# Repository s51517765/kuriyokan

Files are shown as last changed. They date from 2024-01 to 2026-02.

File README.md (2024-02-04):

# Kuriyokan

## 概要 (Overview)

クレジットカードサイズのキーボード

## 実物イメージ (Image)

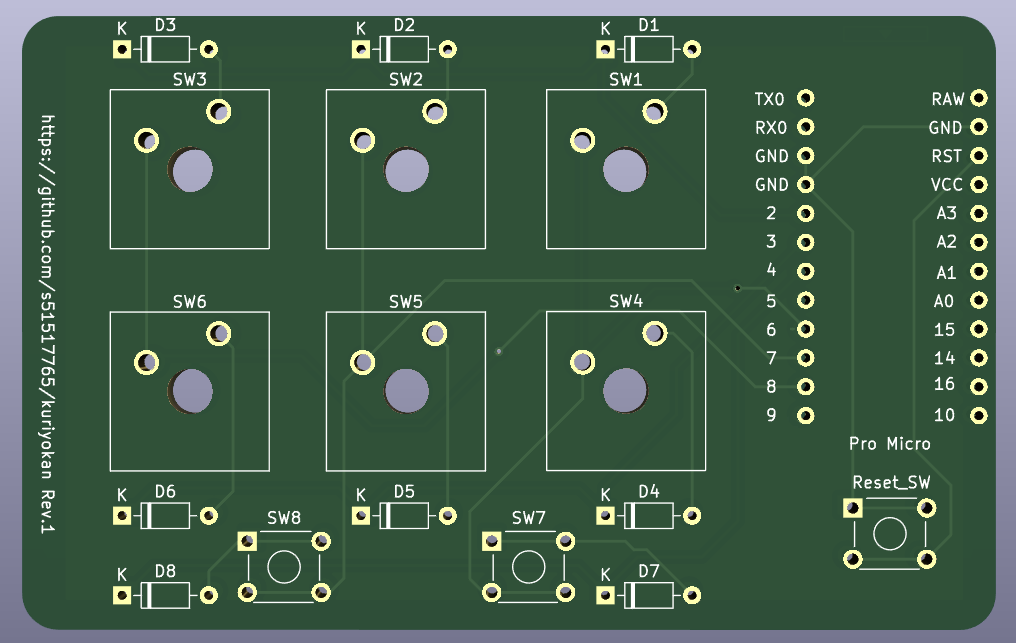
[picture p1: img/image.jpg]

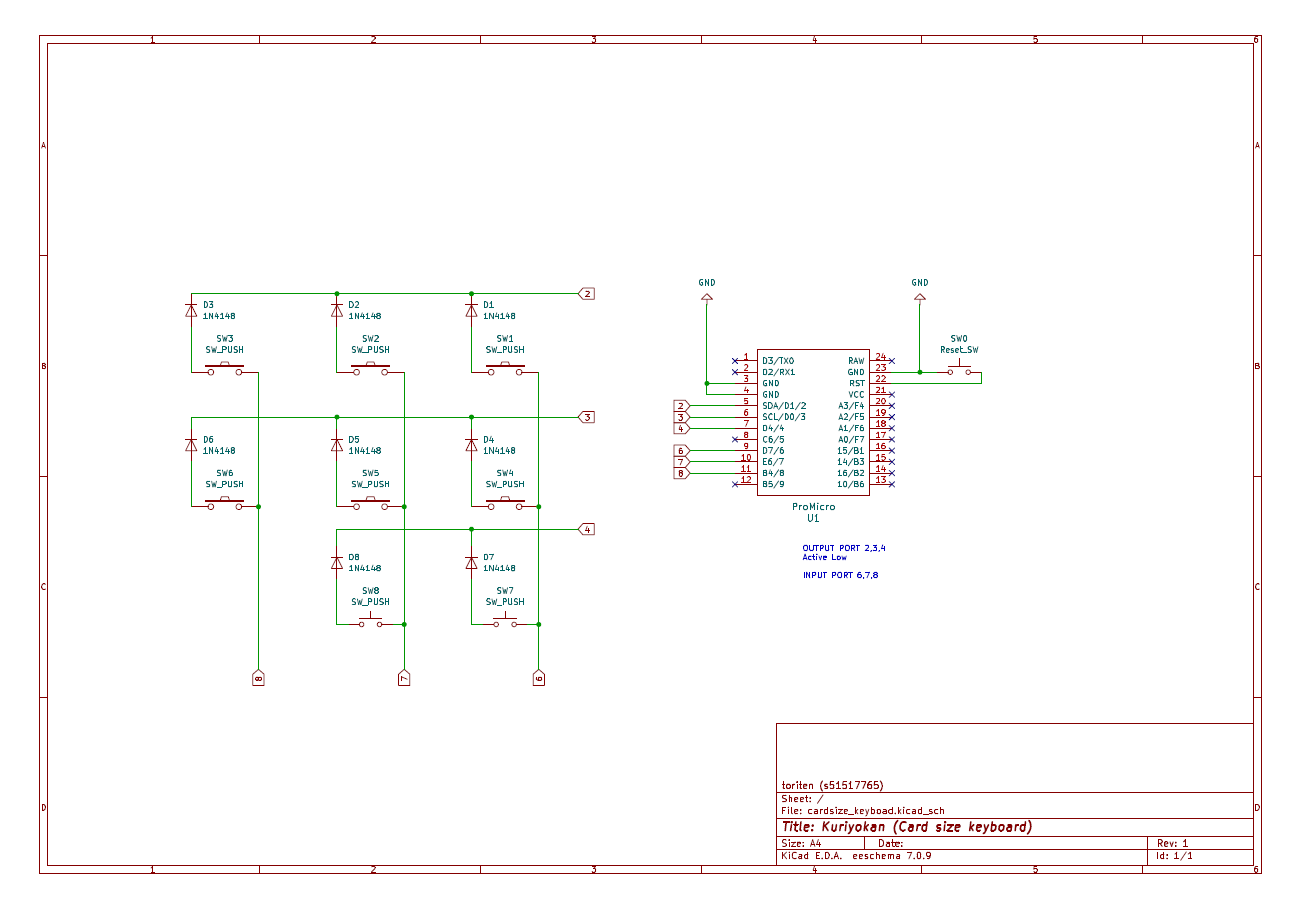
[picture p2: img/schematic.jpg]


## 技術的解説 (Technical explanation)

## 部品リスト（Parts list）

| 部品 | 種類 | 数量 |
| --- | --- | ---- |
| PCB | - | 1 |
| マイコン | Pro Mocro | 1 |
| ピンヘッダ | 12pin | 2 |
| キーボードスイッチ | Cherry MX 互換 | 6 |
| キーキャップ | Cherry MX 互換 | 6 |
| タクトスイッチ | 6mm 角 | 3 |
| ダイオード | 1N4148 | 8 |

## ライセンス (License)

This software is released under the MIT License, see LICENSE.

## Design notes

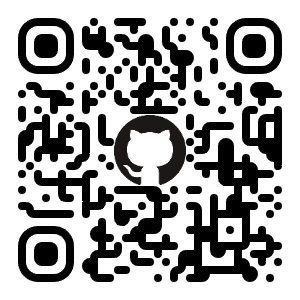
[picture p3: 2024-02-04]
img/QR.png

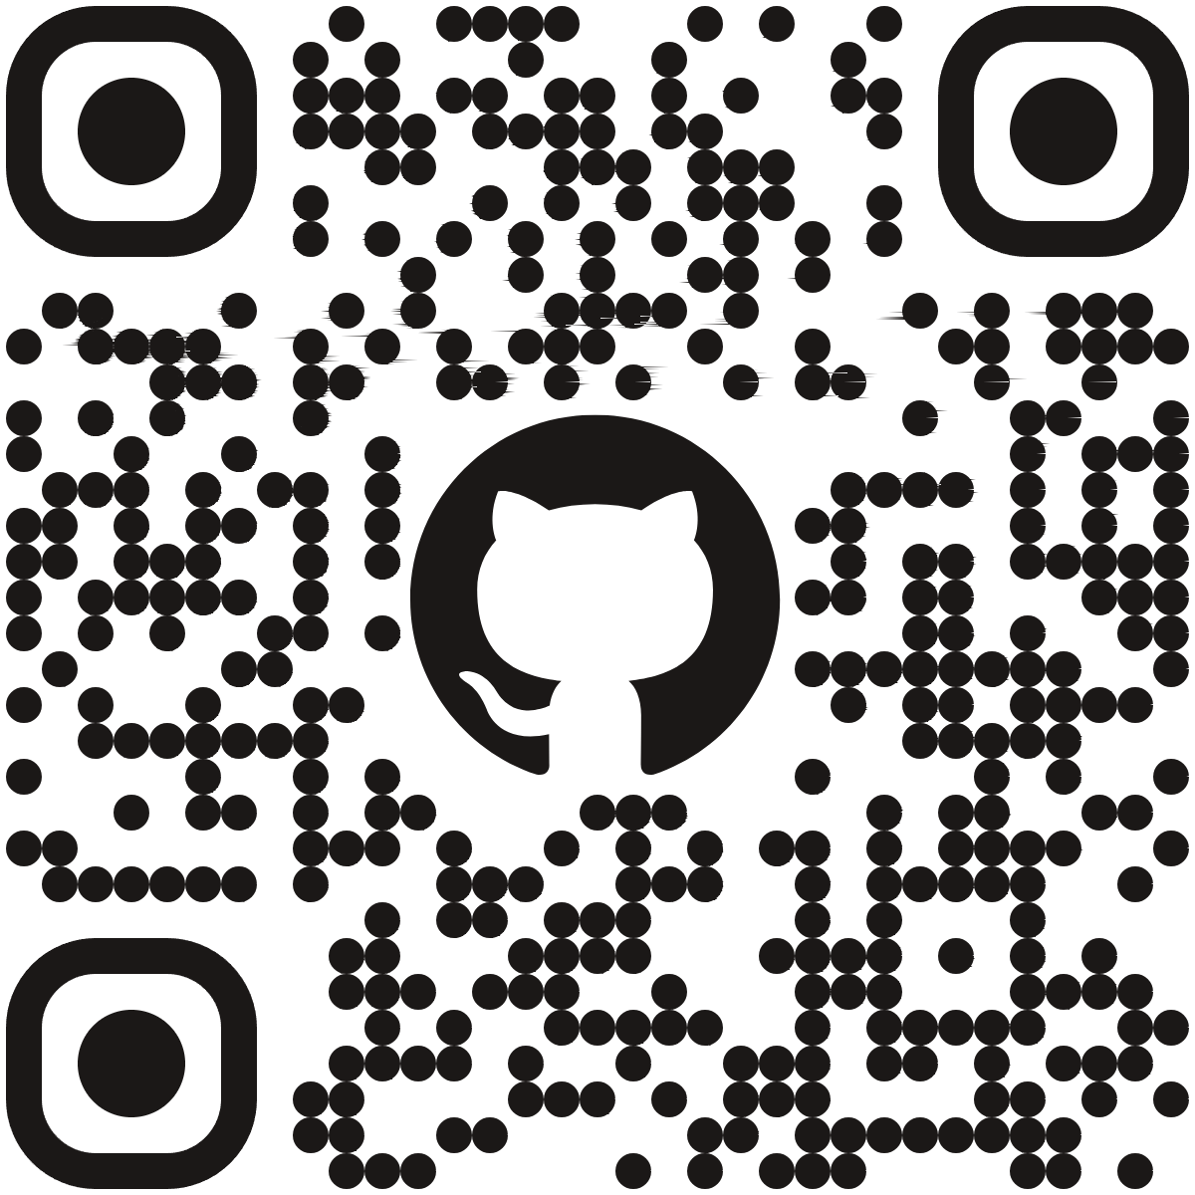
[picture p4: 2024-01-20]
garber/QR.png

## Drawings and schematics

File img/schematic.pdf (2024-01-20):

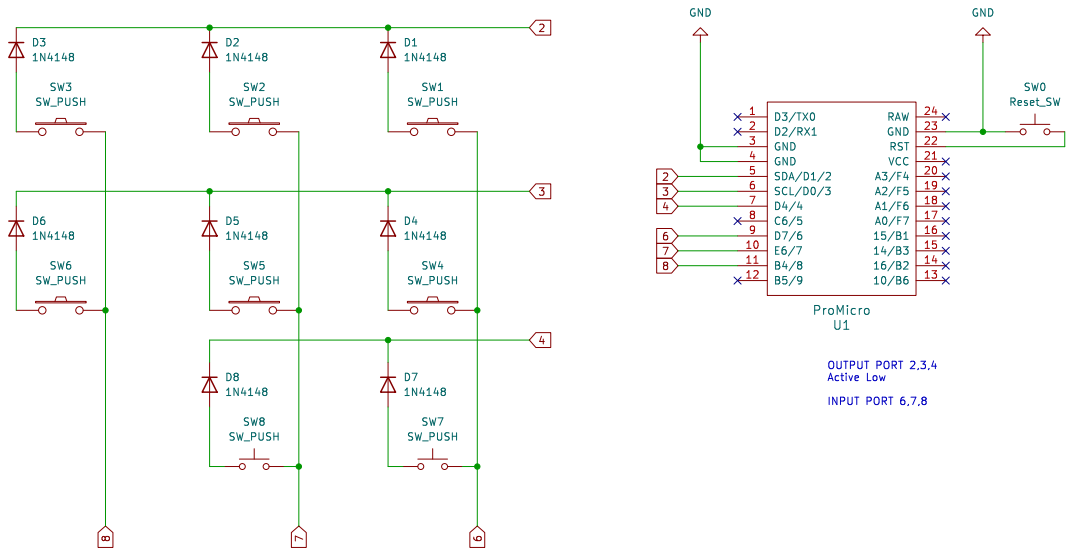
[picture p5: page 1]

Id: 1/1 Title: Kuriyokan (Card size keyboard) File: cardsize_keyboad.kicad_sch Sheet: / toriten (s51517765)

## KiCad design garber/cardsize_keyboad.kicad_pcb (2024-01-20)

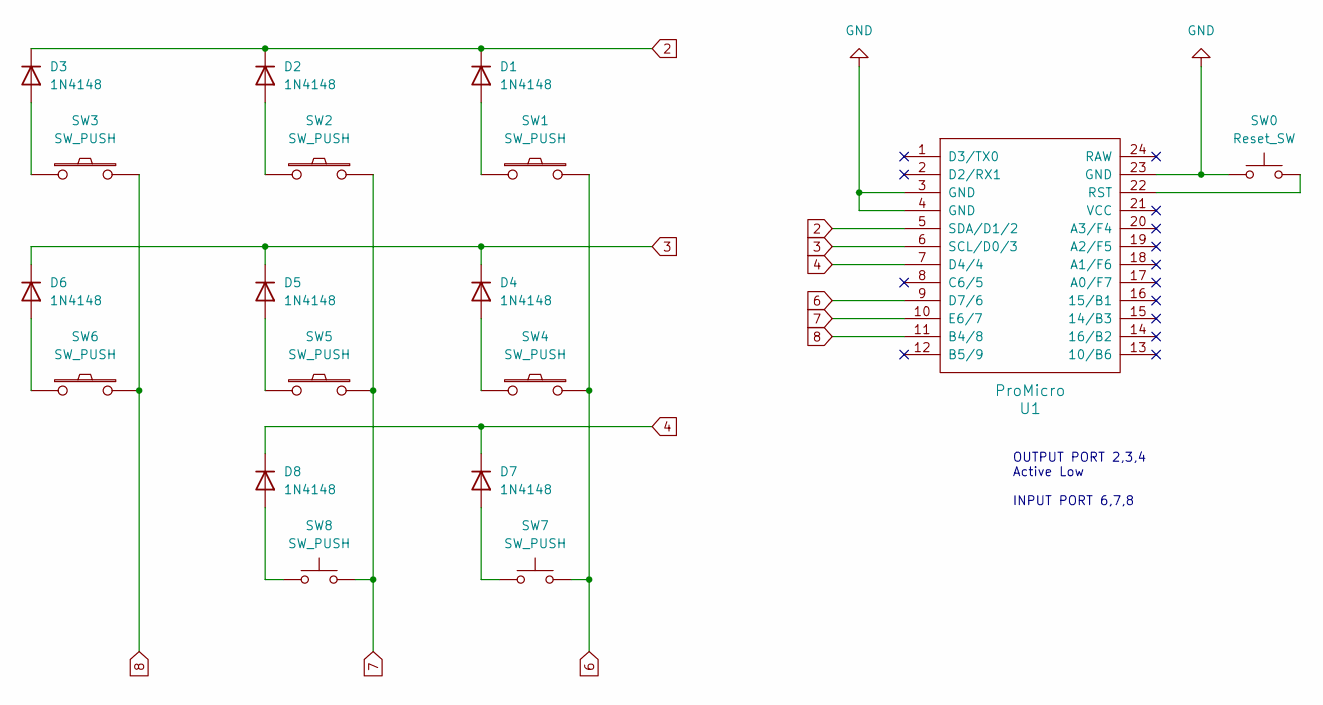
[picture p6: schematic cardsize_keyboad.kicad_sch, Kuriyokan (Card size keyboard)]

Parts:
D1, D2, D3, D4, D5, D6, D7, D8: 1N4148; D_DO-35_SOD27_P7.62mm_Horizontal
SW0: Reset_SW; SW_TH_Tactile_Omron_B3F-10xx
SW1, SW2, SW3, SW4, SW5, SW6: SW_PUSH; SW_Cherry_MX_1.00u_Plate
SW7, SW8: SW_PUSH; SW_TH_Tactile_Omron_B3F-10xx
U1: ProMicro; ProMicro_v3

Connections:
6: SW1.2, SW4.2, SW7.2, U1.9 (D7/6)
7: SW2.2, SW5.2, SW8.2, U1.10 (E6/7)
8: SW3.2, SW6.2, U1.11 (B4/8)
GND: SW0.1, U1.3 (GND), U1.4 (GND), U1.23 (GND)
unnamed: D1.2 (A), SW1.1
unnamed: D1.1 (K), D2.1 (K), D3.1 (K), U1.5 (SDA/D1/2)
unnamed: D2.2 (A), SW2.1
unnamed: D3.2 (A), SW3.1
unnamed: D4.2 (A), SW4.1
unnamed: D4.1 (K), D5.1 (K), D6.1 (K), U1.6 (SCL/D0/3)
unnamed: D5.2 (A), SW5.1
unnamed: D6.2 (A), SW6.1
unnamed: D7.2 (A), SW7.1
unnamed: D7.1 (K), D8.1 (K), U1.7 (D4/4)
unnamed: D8.2 (A), SW8.1
unnamed: SW0.2, U1.22 (RST)

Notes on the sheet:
OUTPUT PORT 2,3,4 Active Low INPUT PORT 6,7,8

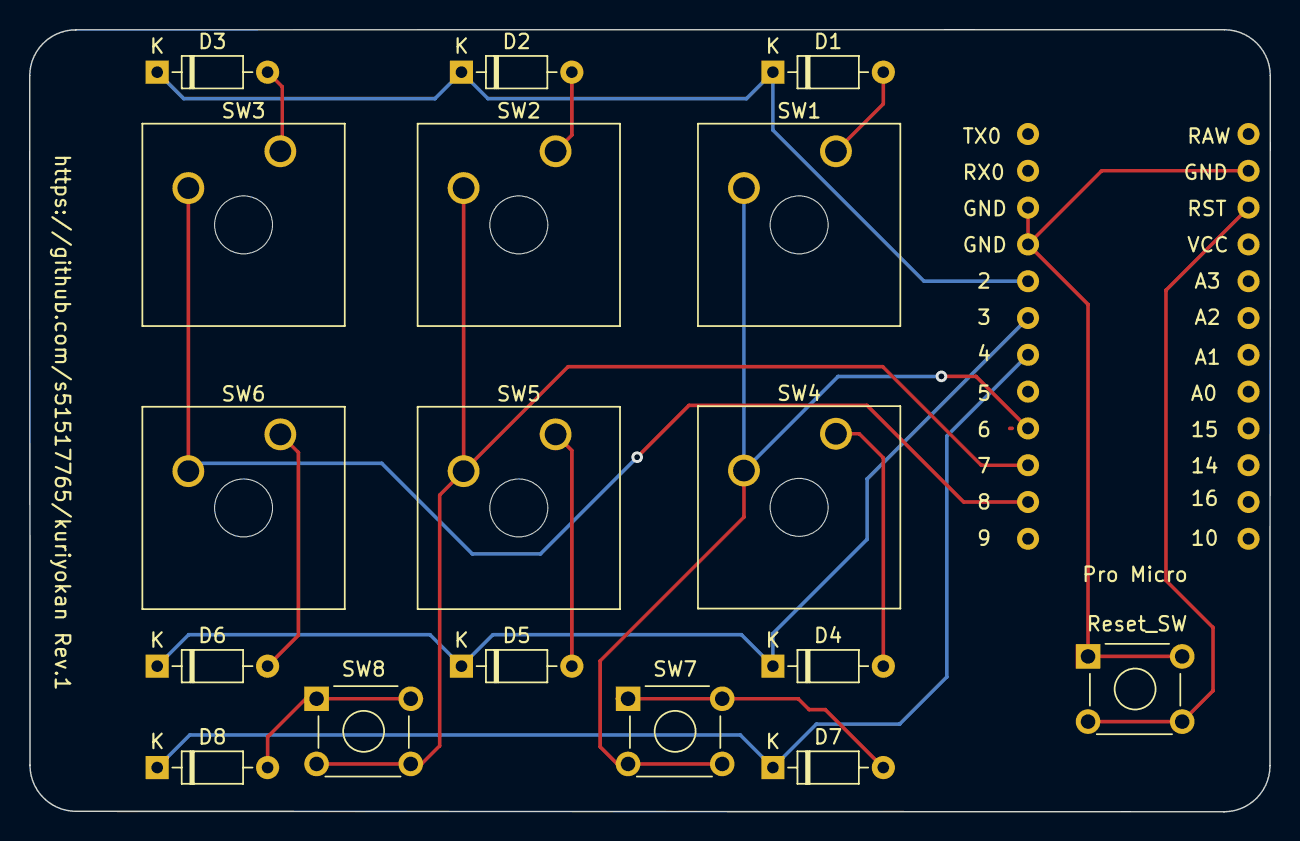
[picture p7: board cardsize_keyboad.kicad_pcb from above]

Board: 2 copper layers, 85.6 x 54.0 mm, 18 parts (1 on the bottom side), 16 nets.

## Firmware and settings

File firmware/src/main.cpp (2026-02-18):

// 認識しないとき、RSTをGNDに2回
// 書き込めないとき、書き込み始めたらRSTをGNDに1回

#include <Keyboard.h>
#include <Mouse.h>
#include "setting.h"

#define BUILTIN_LED 30

const uint8_t OUTPUT_PORT[] = {2, 3, 4}; // 2,3,4
const uint8_t INPUT_PORT[] = {8, 7, 6};  // 5,6,7,8
const uint8_t CN = pow(2, (sizeof(INPUT_PORT) / sizeof(uint8_t)) - 1);

#define MAX_PAGE 2
#define SW_COUNT 9
const uint16_t key_codes[MAX_PAGE][SW_COUNT] = {{SW01, SW02, SW03, SW04, SW05, SW06, SW07, SW08, SW00}, {SW11, SW12, SW13, SW14, SW15, SW16, SW17, SW18, SW10}};
uint8_t key_map_page = 0;

// 文字列定義 必要に応じてサイズは拡大可能
const uint8_t str_codes[2][8] = {{0x6b, 0x75, 0x72, 0x69, KEY_RETURN, NONE, NONE, NONE}, {NONE, NONE, NONE, NONE, NONE, NONE, NONE, NONE}};

void debug_print(uint16_t code)
{
    if (DEBUG_ENABLE)
    {
        Serial.print("0x");
        Serial.println(code, HEX);
    }
}

void setup()
{
    for (uint8_t i = 0; i < sizeof(OUTPUT_PORT); i++)
    {
        pinMode(OUTPUT_PORT[i], OUTPUT);
        digitalWrite(OUTPUT_PORT[i], HIGH);
    }
    for (uint8_t i = 0; i < sizeof(INPUT_PORT); i++)
    {
        pinMode(INPUT_PORT[i], INPUT_PULLUP);
    }
    Keyboard.releaseAll();
    if (DEBUG_ENABLE)
    {
        Serial.begin(115200);
    }
    else
    {
        pinMode(BUILTIN_LED, INPUT);
    }
    //ホイールスクロール用
    Mouse.begin();
}

uint16_t key_scan()
{
    uint16_t key_pressed = 0;
    for (uint8_t col = 0; col < sizeof(OUTPUT_PORT); col++)
    {
        digitalWrite(OUTPUT_PORT[col], LOW);
        uint16_t row_data = 0;
        for (uint8_t row = 0; row < sizeof(INPUT_PORT); row++)
        {
            row_data |= (digitalRead(INPUT_PORT[row]) ? 0 : CN >> row);
        }
        key_pressed |= (row_data << (sizeof(INPUT_PORT) * col));
        digitalWrite(OUTPUT_PORT[col], HIGH);
    }
    return key_pressed;
}

void loop()
{
    static uint8_t last_key_pressed = 0;
    uint16_t key_pressed = key_scan();
    uint16_t change = key_pressed ^ last_key_pressed;
    if (change)
    {
        uint16_t mask = 1;
        uint16_t code;

        for (uint8_t i = 0; i < sizeof(key_codes[0]); i++)
        {
            if (change & mask)
            {
                code = key_codes[key_map_page][i];

                if (key_pressed & mask)
                {
                    if (code == KEY_MAP_PAGE_TOGGLE)
                    {
                        key_map_page = (key_map_page + 1) % MAX_PAGE;
                        debug_print(0xFFFF);
                    }
                    else if((code & 0x2000) !=0){
                        // ホイールスクロール
                        switch(code)
                        {
                        case WHEEL_SCROLL_UP:
                            Mouse.move(0, 0, 1); // 上スクロール
                            break;
                        case WHEEL_SCROLL_DOWN:
                            Mouse.move(0, 0, -1); // 上スクロール
                            break;
                        case WHEEL_SCROLL_UP_CTRL: 
                            Keyboard.press(KEY_LEFT_CTRL);    
                            Mouse.move(0, 0, 1); // 上スクロール
                            break;
                        case WHEEL_SCROLL_UP_SHIFT:
                            Keyboard.press(KEY_LEFT_SHIFT);   
                            Mouse.move(0, 0, 1); // 上スクロール    
                            break;
                        case WHEEL_SCROLL_DOWN_CTRL:
                            Keyboard.press(KEY_LEFT_CTRL);    
                            Mouse.move(0, 0, -1); // 下スクロール
                            break;
                        case WHEEL_SCROLL_DOWN_SHIFT:
                            Keyboard.press(KEY_LEFT_SHIFT);   
                            Mouse.move(0, 0, -1); // 下スクロール
                            break;
                        default:
                            break;
                        }
                    }
                    else if ((code & STR_0) != 0)
                    {
                        // 文字列
                        for (uint8_t i = 0; i < sizeof(str_codes[0]) / sizeof(str_codes[0][0]); i++)
                        {
                            Keyboard.press(str_codes[code & 0x0F][i]);
                            debug_print(str_codes[code & 0x0F][i]);
                            delay(10);
                        }
                    }
                    else if (code == CTRL_ALT_DELETE)
                    {
                        Keyboard.press(KEY_LEFT_CTRL);
                        Keyboard.press(KEY_LEFT_ALT);
                        Keyboard.press(KEY_DELETE);
                    }
                    else if (code & 0x100)
                    {
                        Keyboard.press(KEY_LEFT_CTRL);
                    }
                    else if (code & 0x200)
                    {
                        Keyboard.press(KEY_LEFT_SHIFT);
                    }
                    else if (code & 0x400)
                    {
                        Keyboard.press(KEY_LEFT_GUI); // WINDOWS
                    }
                    else if (code & 0x800)
                    {
                        Keyboard.press(KEY_LEFT_ALT);
                    }
                    Keyboard.press(code & 0xFF);

                    delay(10);
                    debug_print(code);
                    Keyboard.releaseAll();
                }
            }
            mask = mask << 1;
        }
        last_key_pressed = key_pressed;
    }
    delay(DELAY_MS);
}

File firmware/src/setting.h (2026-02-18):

#include "key_def.h"

// Key Map
// https://www.edu.i.hosei.ac.jp/~sigesada/kyouzai/mojicodehenkan.html
/*
 *  Key map
 * SW3 SW2 SW1
 * SW6 SW5 SW4
 *   SW8 SW7
 */

// KEY MAP 1st PAGE
#define SW01 CTRL_V
#define SW02 CTRL_F
#define SW03 CTRL_A
#define SW04 CTRL_C
#define SW05 CTRL_X
#define SW06 CTRL_Z
#define SW07 KEY_MAP_PAGE_TOGGLE
#define SW08 WIN_D
#define SW00 // This Keyboard has 8 keys. Not assigned.
// KEY MAP 2nd PAGE
#define SW11 WHEEL_SCROLL_UP
#define SW12 WHEEL_SCROLL_UP_SHIFT
#define SW13 WHEEL_SCROLL_DOWN
#define SW14 WHEEL_SCROLL_DOWN_CTRL
#define SW15 WHEEL_SCROLL_DOWN_SHIFT
#define SW16 WHEEL_SCROLL_UP_CTRL
#define SW17 KEY_MAP_PAGE_TOGGLE
#define SW18 WIN_D
#define SW10 // This Keyboard has 8 keys. Not assigned.

// Setting
#define DEBUG_ENABLE 0 // debug_print and BUILTIN_LED 0 or 1
#define DELAY_MS 100

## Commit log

2024-02-04 FW first commit
    [cardsize_keyboad-B_Cu.gbr, cardsize_keyboad-B_Mask.gbr, cardsize_keyboad-B_Paste.gbr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]
2024-05-01 文字列対応、リファクタリング
2025-10-25 ホイールスクロール機能追加
2025-10-25 キーマップページ追加
2026-02-18 ホイルスクロールを追加
